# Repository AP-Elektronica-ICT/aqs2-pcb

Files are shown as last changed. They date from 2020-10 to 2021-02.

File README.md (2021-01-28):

# Schema airsensor
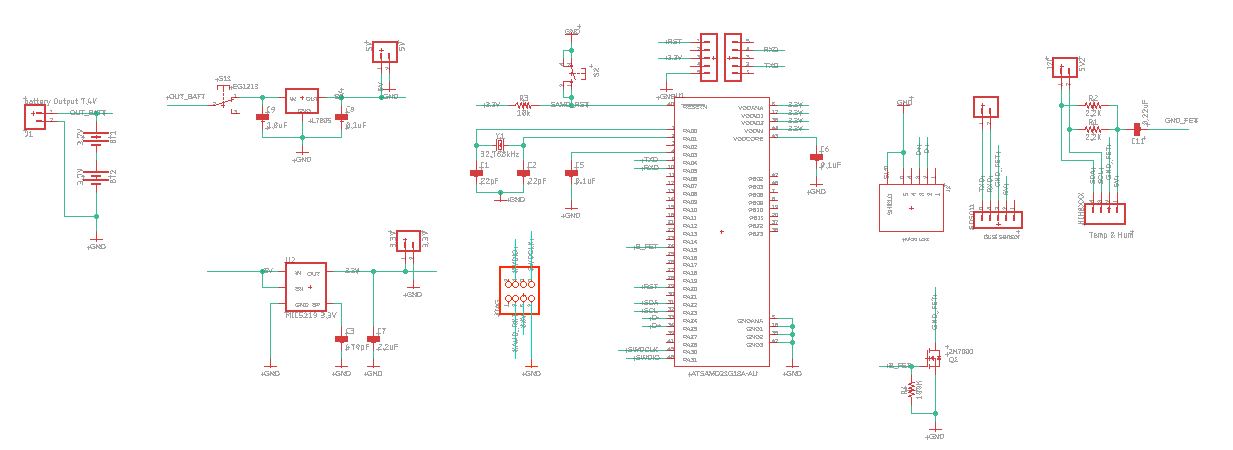
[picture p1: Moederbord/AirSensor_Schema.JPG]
schema airsensor


# Schema LoRaWAN
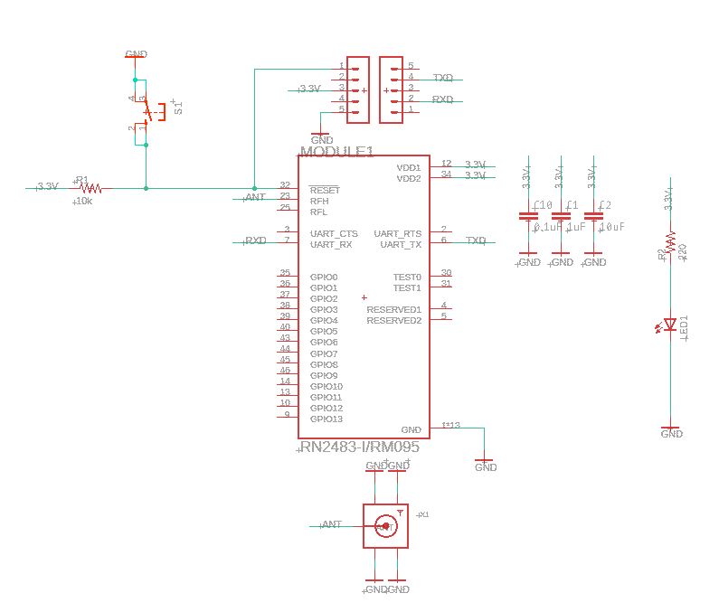
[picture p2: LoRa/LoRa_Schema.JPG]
schema LoRa


# Schema HIH8xxx
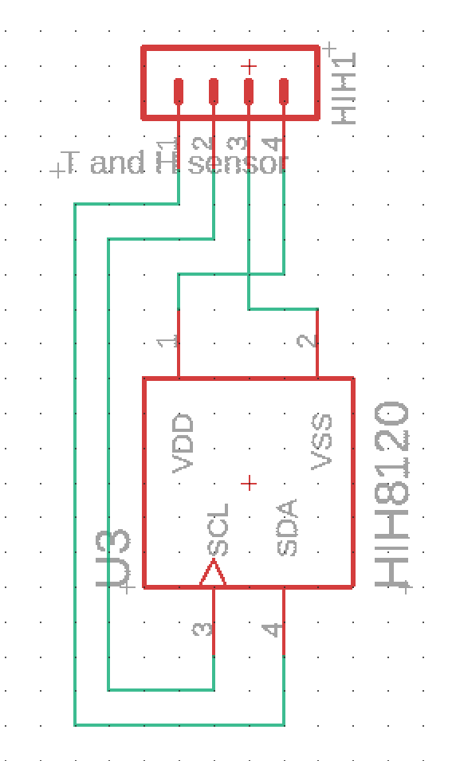
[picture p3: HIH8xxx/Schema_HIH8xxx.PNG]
Schema HIH8xxx


# Schema JTAG
<<<<<<< HEAD
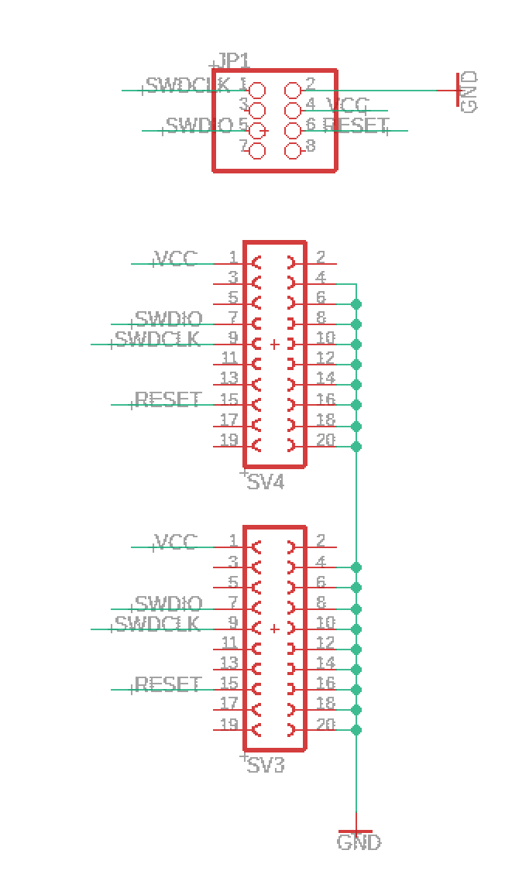
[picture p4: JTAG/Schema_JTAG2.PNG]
schema JTAG

=======
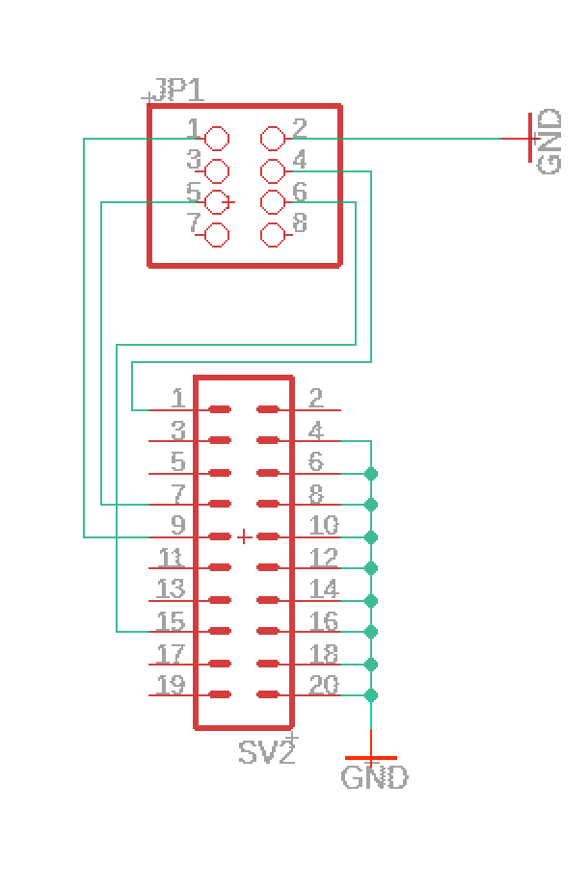
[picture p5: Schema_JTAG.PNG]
schema JTAG

>>>>>>> c74764702c0ad45f76e91693a2fbca707ce8f4d9

# PCB airsensor
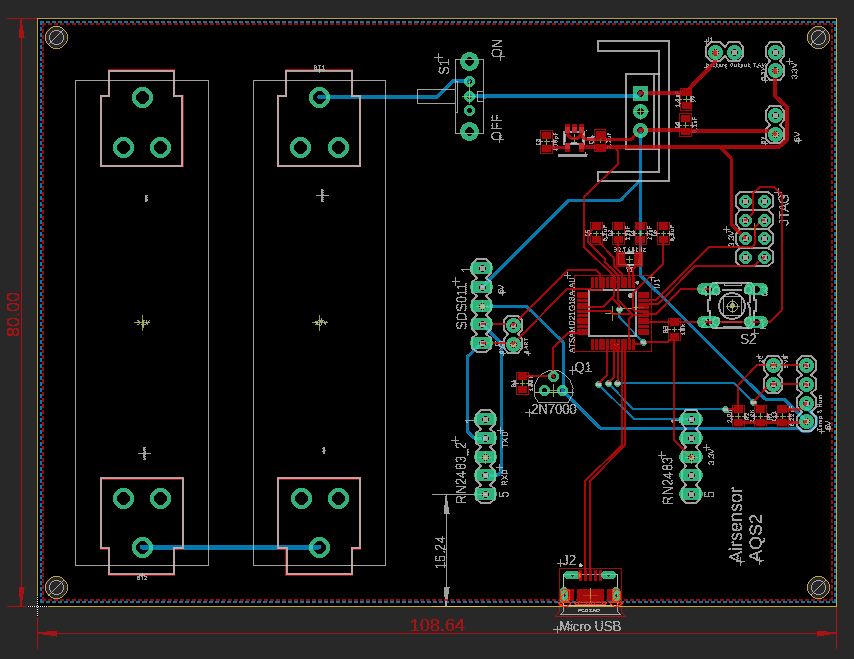
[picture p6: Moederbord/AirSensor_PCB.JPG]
PCB airsensor


# PCB LoRaWAN
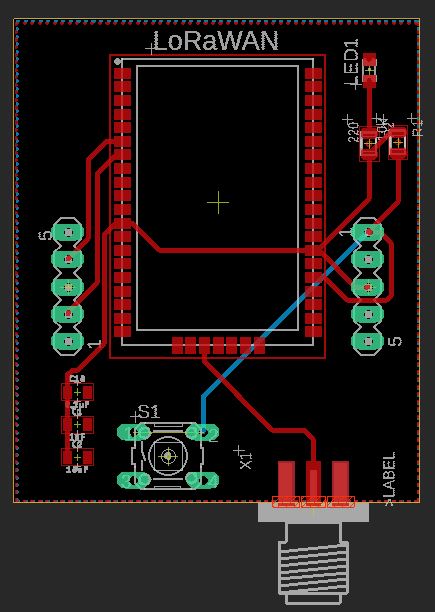
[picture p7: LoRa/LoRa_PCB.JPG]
PCB LoraWAN


# PCB HIH8xxx
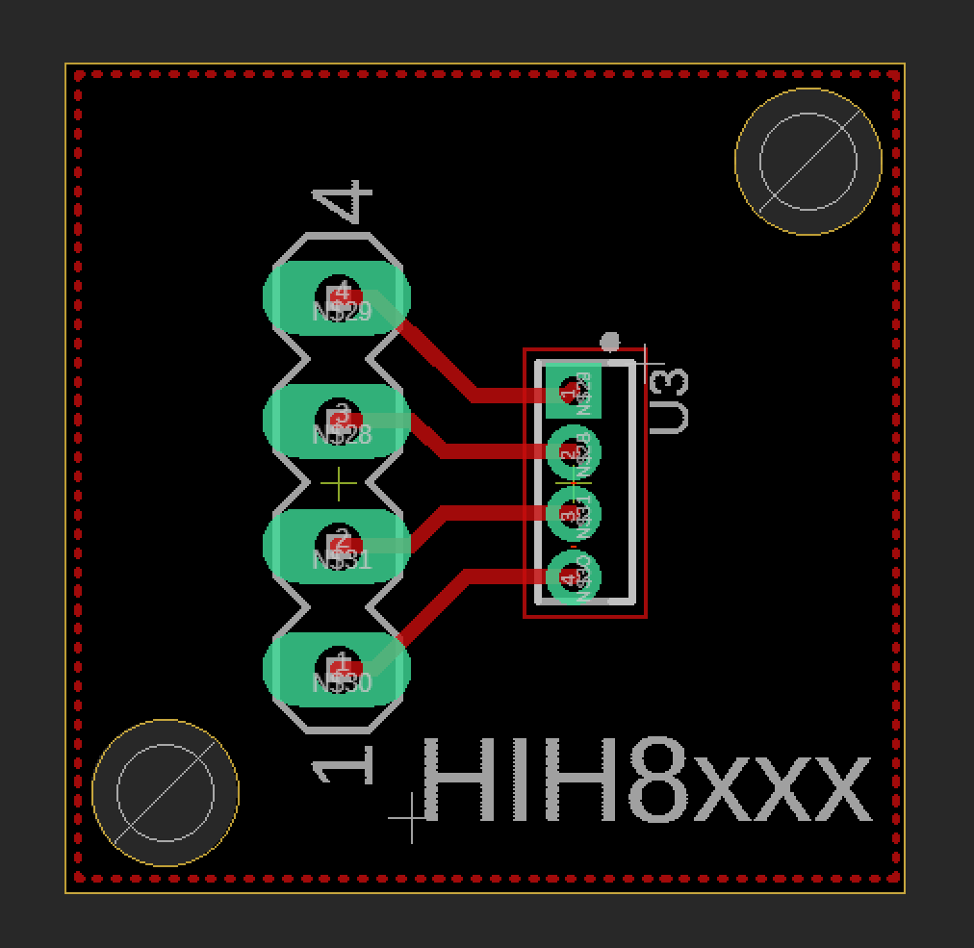
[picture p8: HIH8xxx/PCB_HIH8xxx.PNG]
PCB HIH8xxx


# PCB JTAG
<<<<<<< HEAD
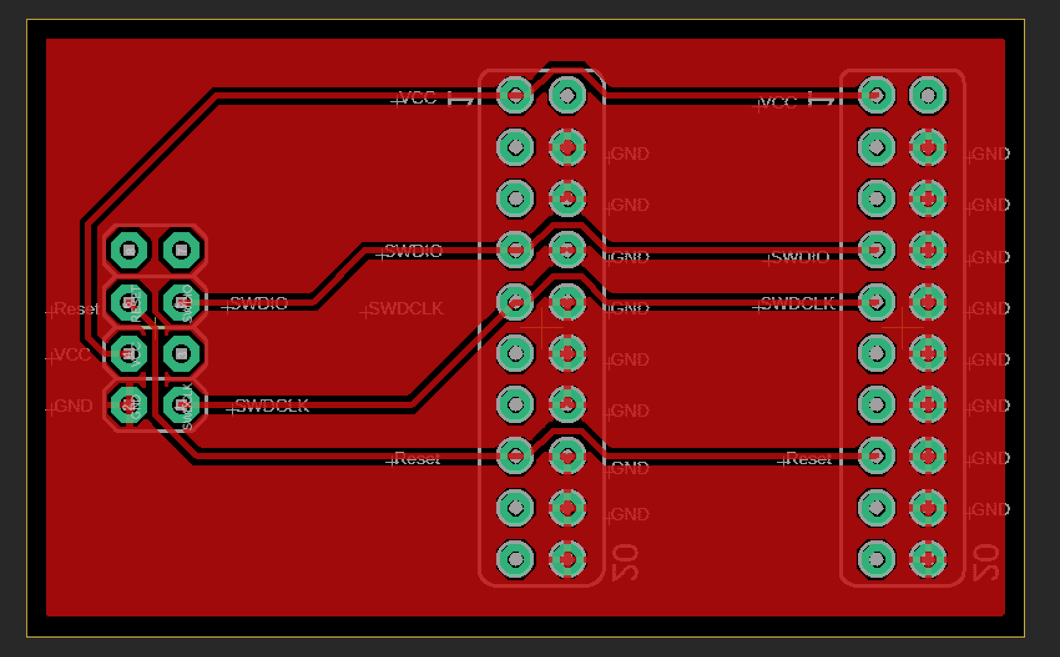
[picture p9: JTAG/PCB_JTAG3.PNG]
PCB JTAG

=======
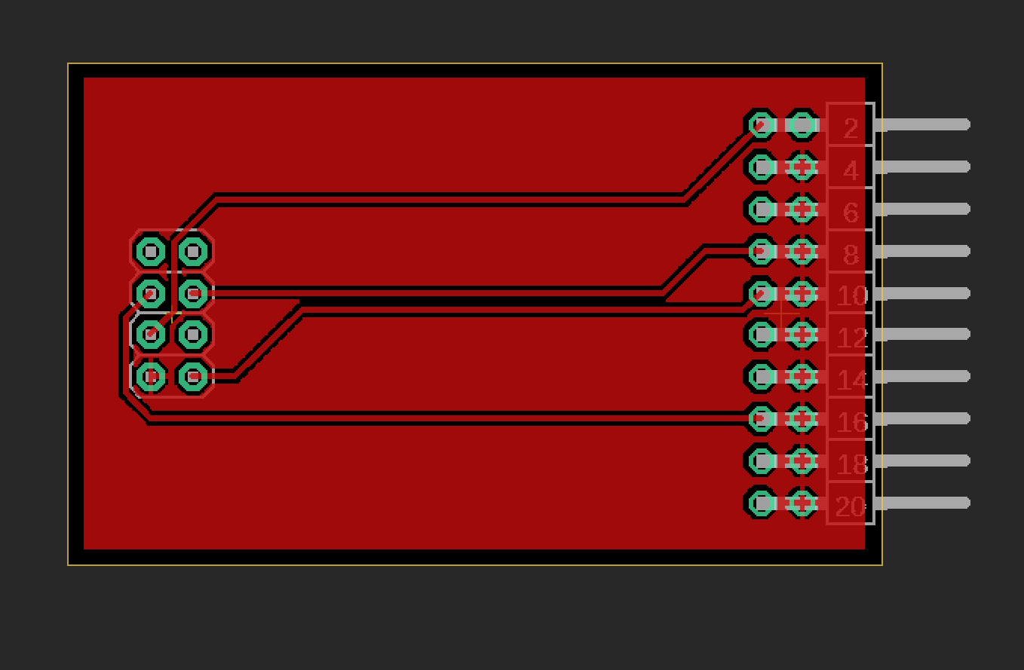
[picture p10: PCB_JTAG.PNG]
PCB JTAG

>>>>>>> c74764702c0ad45f76e91693a2fbca707ce8f4d9

# 3D airsensor
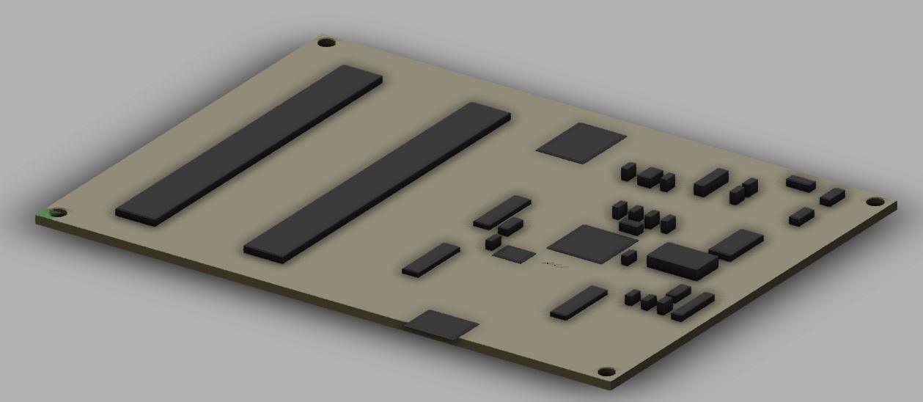
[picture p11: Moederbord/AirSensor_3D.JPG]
3D airsensor


# 3D LoRaWAN
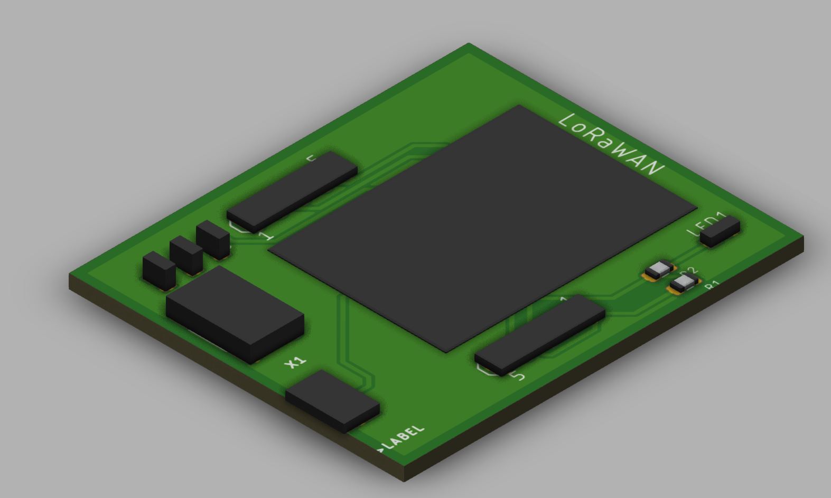
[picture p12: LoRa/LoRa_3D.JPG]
3D LoraWAN


# 3D HIH8xxx
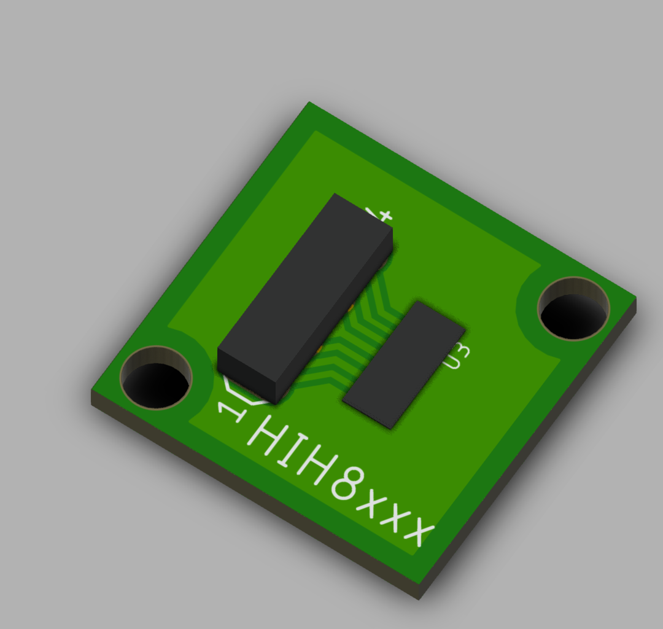
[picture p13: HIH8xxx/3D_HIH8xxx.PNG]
3D HIH8xxx


# 3D JTAG
<<<<<<< HEAD
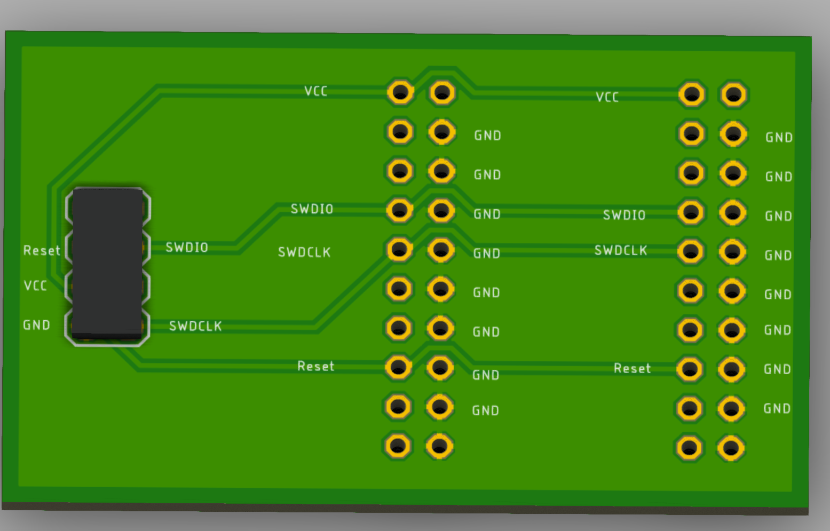
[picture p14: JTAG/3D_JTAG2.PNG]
3D JTAG

=======
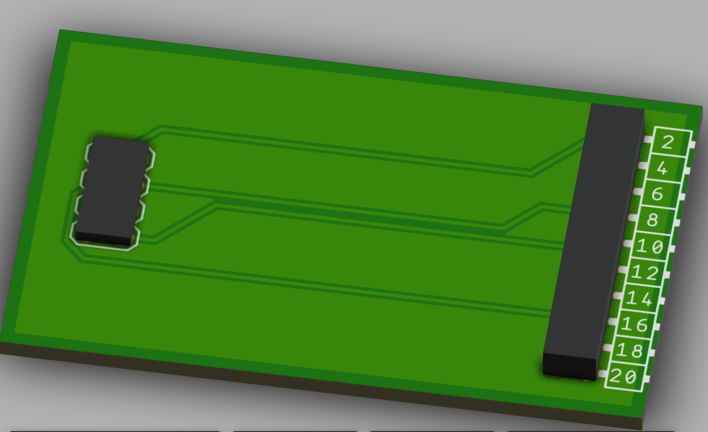
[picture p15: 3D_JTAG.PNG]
3D JTAG


>>>>>>> c74764702c0ad45f76e91693a2fbca707ce8f4d9

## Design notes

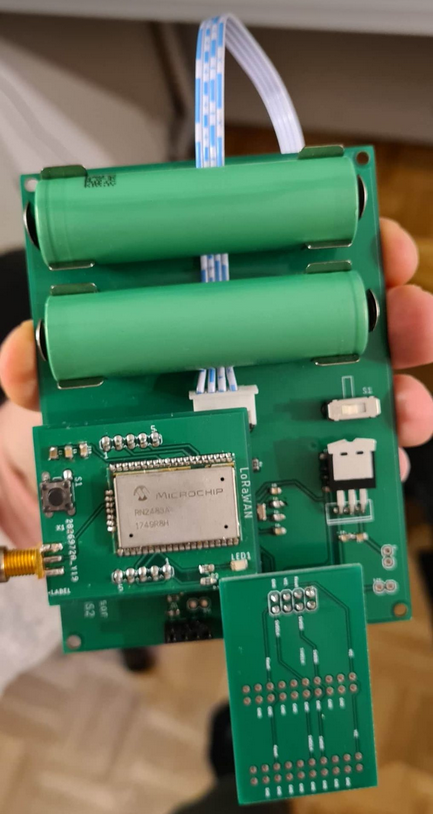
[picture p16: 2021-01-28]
PCB_V2.PNG

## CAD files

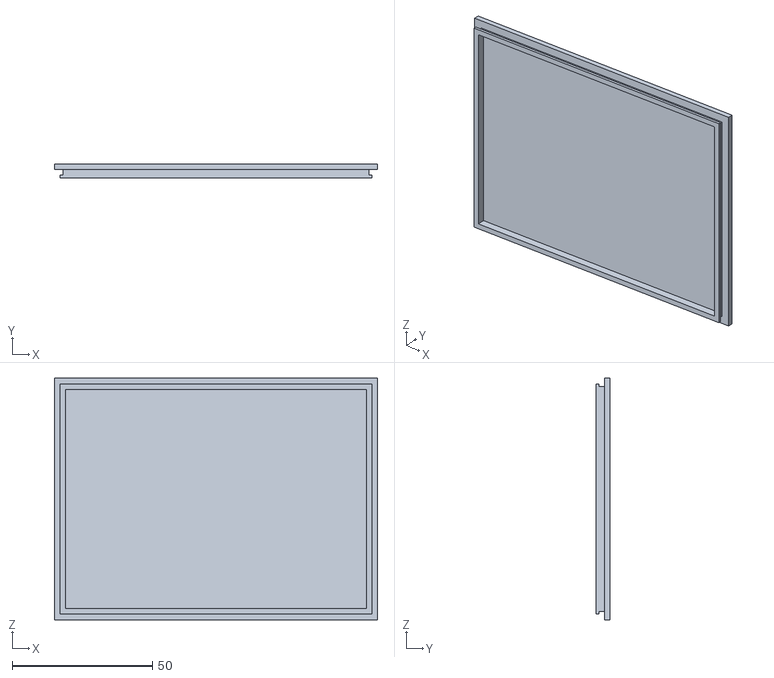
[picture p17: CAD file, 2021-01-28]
frame/cap.stl
115.0 x 5.00 x 86.0

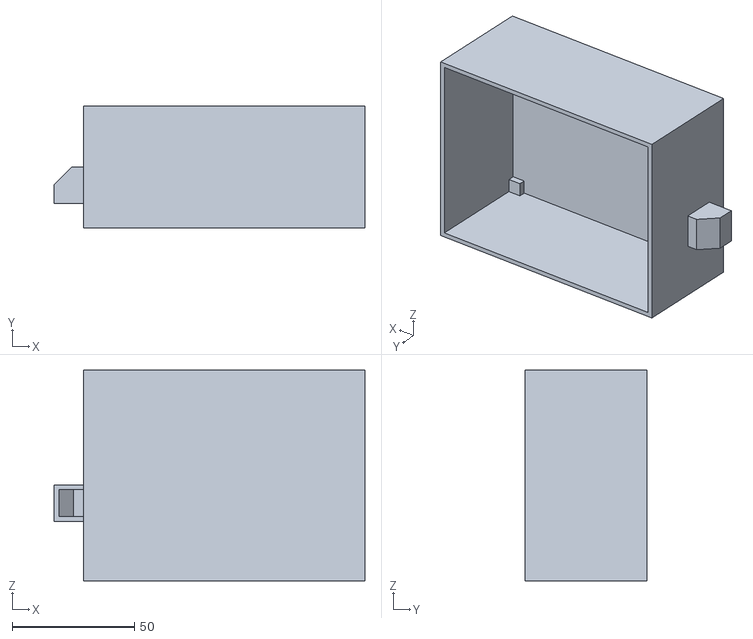
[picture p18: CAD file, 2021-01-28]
frame/box.stl
127.0 x 50.0 x 86.0

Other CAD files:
frame/box.ipt
frame/cap.ipt

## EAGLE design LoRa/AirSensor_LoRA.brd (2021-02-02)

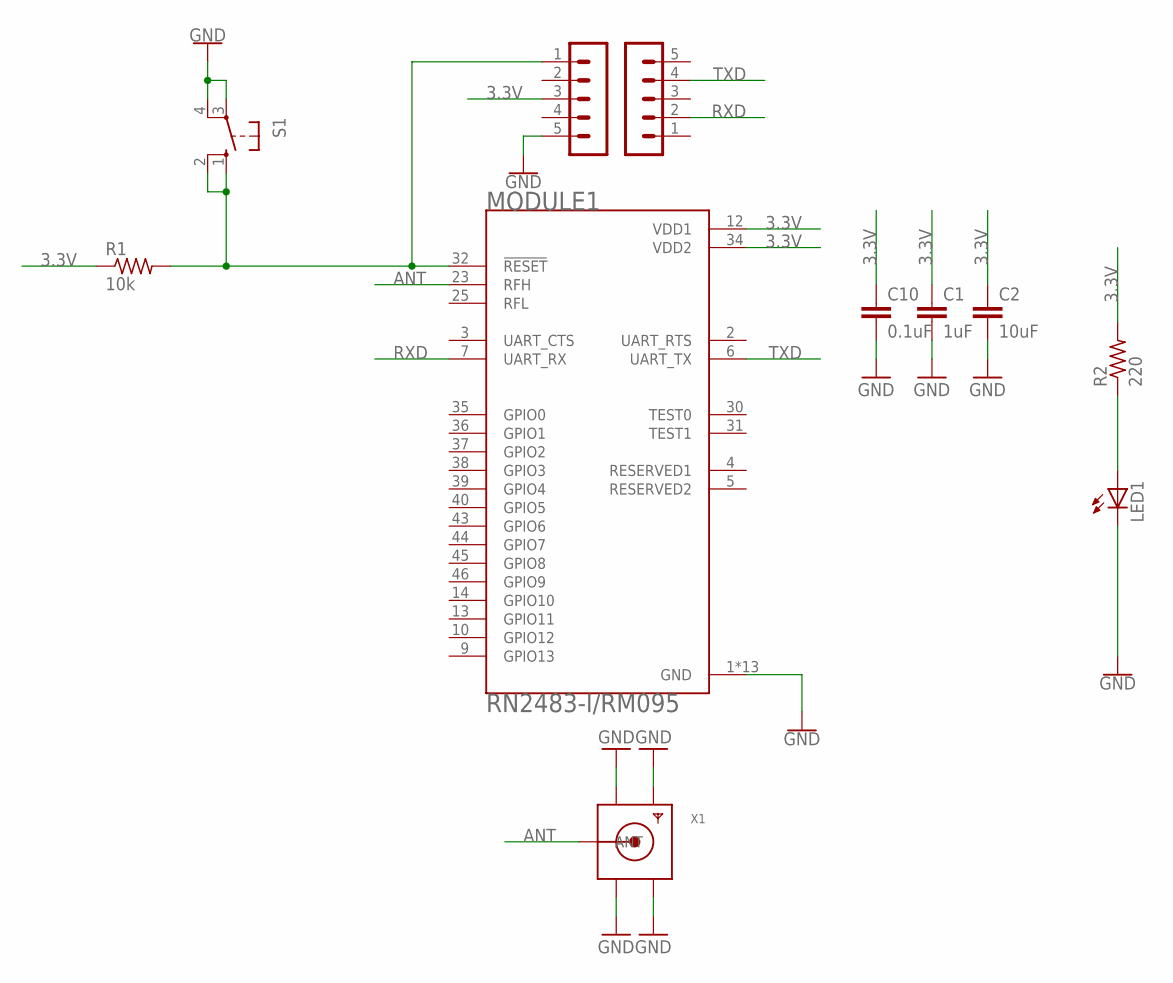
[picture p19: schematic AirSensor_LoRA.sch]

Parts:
C1: 1uF; 0805
C2: 10uF; 0805
C10: 0.1uF; 0805
LED1: LEDCHIPLED_0805; CHIPLED_0805
MODULE1: RN2483-I/RM095; MICROCHIP_RN2483-I/RM095
R1: 10k; RES_0805
R2: 220; RES_0805
RFM95W_1: LoRa_1; MA05-1
RFM95W_2: LoRa_2; MA05-1
S1: 10-XX; B3F-10XX
X1: SMACONNECTOR_EDGE; SMA_EDGELAUNCH

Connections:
3.3V: C1.1, C2.1, C10.1, MODULE1.12 (VDD1), MODULE1.34 (VDD2), R1.1, R2.2, RFM95W_1.3
ANT: MODULE1.23 (RFH), X1.P (ANT)
GND: C1.2, C2.2, C10.2, LED1.C, MODULE1.1 (GND), MODULE1.8 (GND), MODULE1.11 (GND), MODULE1.20 (GND), MODULE1.21 (GND), MODULE1.22 (GND), MODULE1.24 (GND), MODULE1.26 (GND), MODULE1.27 (GND), MODULE1.28 (GND), MODULE1.33 (GND), MODULE1.41 (GND), MODULE1.47 (GND), RFM95W_1.5, S1.3, S1.4 (P1), X1.GND@1 (GND4), X1.GND@2 (GND3), X1.GND@3 (GND2), X1.GND@4 (GND1)
unnamed: LED1.A, R2.1
unnamed: MODULE1.32 (!RESET), R1.2, RFM95W_1.1, S1.1 (S), S1.2 (S1)
RXD: MODULE1.7 (UART_RX), RFM95W_2.2
TXD: MODULE1.6 (UART_TX), RFM95W_2.4

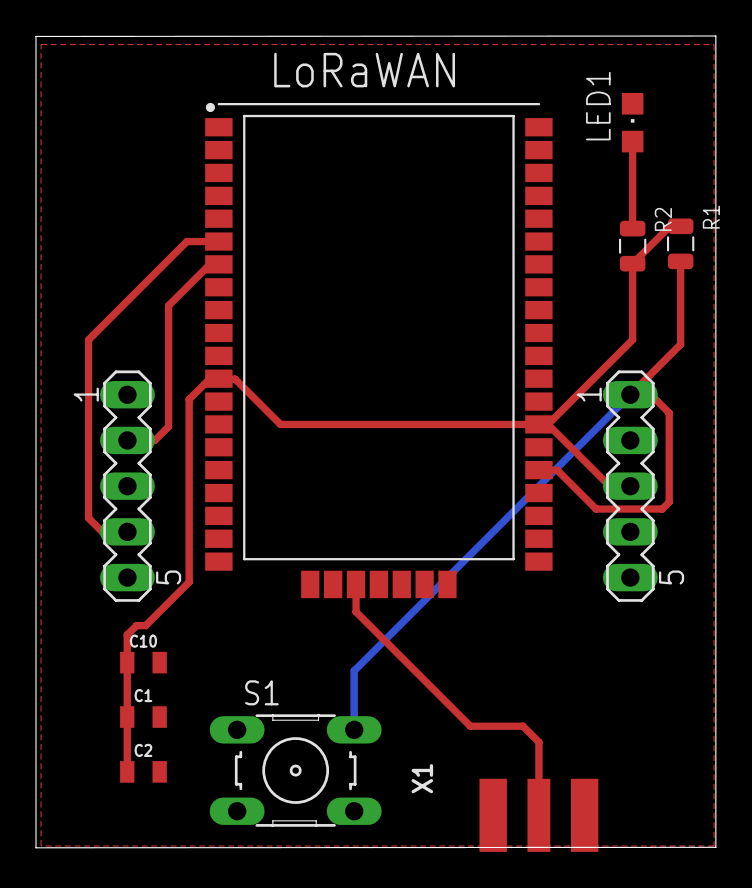
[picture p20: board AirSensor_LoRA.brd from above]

Board: 2 copper layers, 37.8 x 45.1 mm, 11 parts (0 on the bottom side), 7 nets.

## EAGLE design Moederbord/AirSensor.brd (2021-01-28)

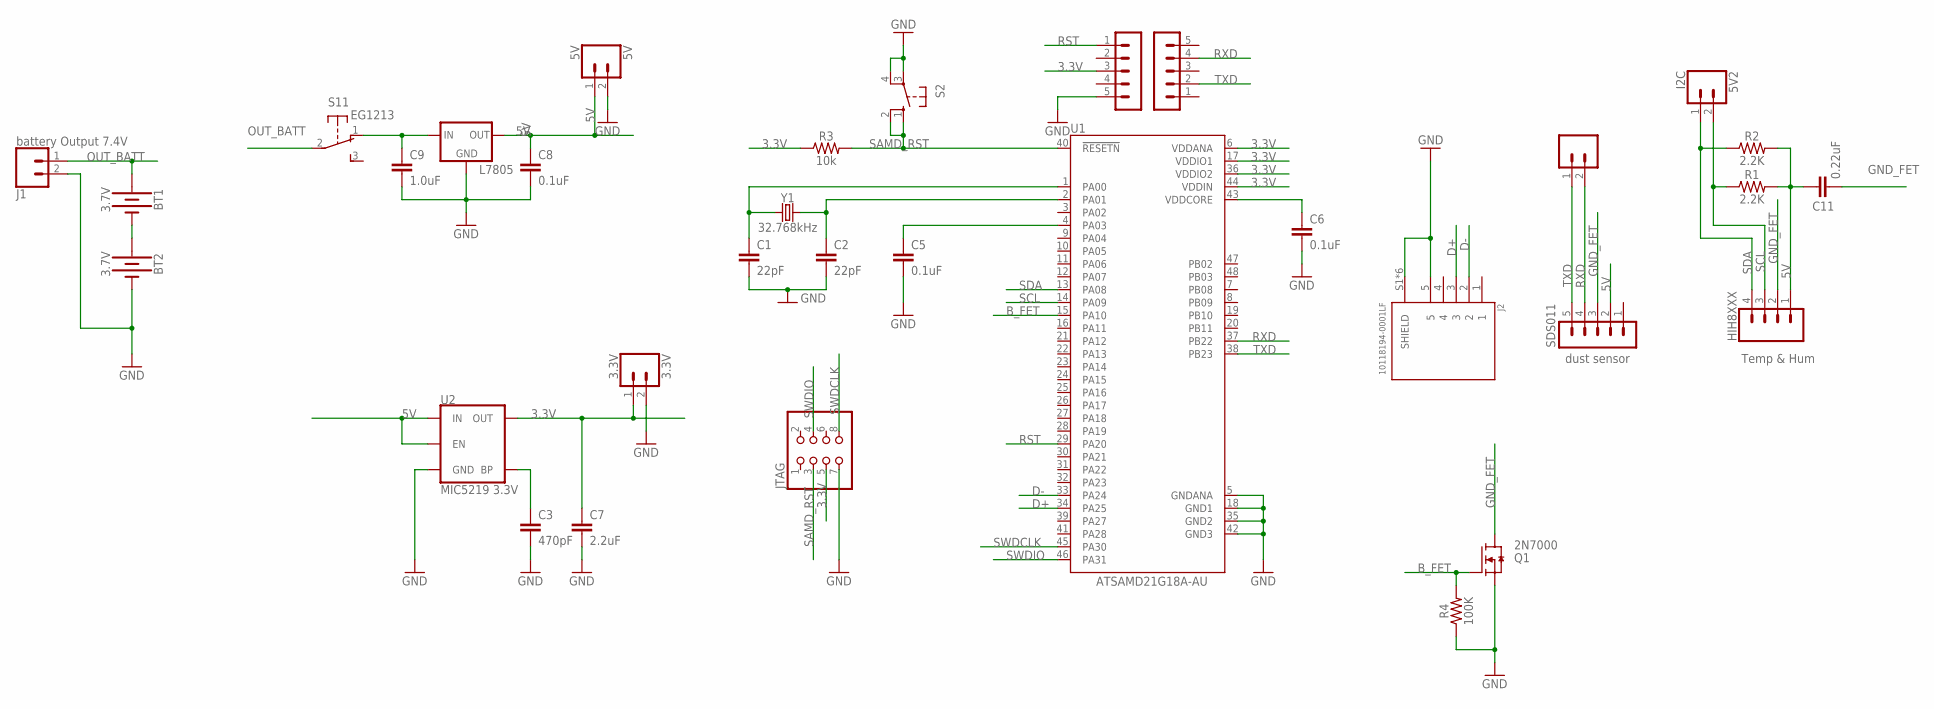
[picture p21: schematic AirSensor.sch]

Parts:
3.3V: 3.3V; 1X02
5V: 5V; 1X02
5V1: UART; 1X02
5V2: I2C; 1X02
BT1, BT2: 3.7V; BATTERY_18650-HOLDER
C1, C2: 22pF; 0805
C3: 470pF; 0805
C5, C6, C8: 0.1uF; 0805
C7: 2.2uF; 0805
C9: 1.0uF; 0805
C11: 0.22uF; 0805
HIH8XXX: Temp & Hum; 1X04
J1: battery Output 7.4V; 1X02
J2: 10118194-0001LF; AMPHENOL_10118194-0001LF
JTAG: PINHD-2X4; 2X04
L7805: V_REG_78XXSINK; TO220-IGO
Q1: 2N7000; TO92
R1, R2: 2.2K; 0805
R3: 10k; 0805
R4: 100K; 0805
RN2483: LoRa1; MA05-1
RN2483_2: LoRa_2; MA05-1
S1: EG1213
S2: 10-XX; B3F-10XX
SDS011: dust sensor; MA05-1
U1: ATSAMD21G18A-AU; QFP50P900X900X120-48N
U2: MIC5219 3.3V; SOT23-5
Y1: 32.768kHz; CRYSTAL-SMD-3.2X1.5MM

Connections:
3.3V: 3.3V.1, C7.1, JTAG.5, R3.1, RN2483.3, U1.6 (VDDANA), U1.17 (VDDIO1), U1.36 (VDDIO2), U1.44 (VDDIN), U2.5 (OUT)
5V: 5V.1, C8.1, C11.1, HIH8XXX.1, L7805.OUT, R1.2, R2.2, SDS011.2, U2.1 (IN), U2.3 (EN)
B_FET: Q1.2 (G), R4.2, U1.15 (PA10)
D+: J2.3, U1.34 (PA25)
D-: J2.2, U1.33 (PA24)
GND: 3.3V.2, 5V.2, BT2.GND@1 (-), C1.2, C2.2, C3.2, C5.2, C6.2, C7.2, C8.2, C9.2, J1.2, J2.5, J2.S1 (SHIELD), J2.S2 (SHIELD), J2.S3 (SHIELD), J2.S4 (SHIELD), J2.S5 (SHIELD), J2.S6 (SHIELD), JTAG.7, L7805.GND, Q1.1 (S), R4.1, RN2483.5, S2.3, S2.4 (P1), U1.5 (GNDANA), U1.18 (GND1), U1.35 (GND2), U1.42 (GND3), U2.2 (GND)
GND_FET: C11.2, HIH8XXX.2, Q1.3 (D), SDS011.3
unnamed: C5.1, U1.4 (PA03)
unnamed: C6.1, U1.43 (VDDCORE)
unnamed: C1.1, U1.1 (PA00), Y1.P$1 (1)
unnamed: C3.1, U2.4 (BP)
unnamed: BT1.GND@1 (-), BT2.PWR@1 (+)
unnamed: C2.1, U1.2 (PA01), Y1.P$2 (2)
OUT_BATT: BT1.PWR@1 (+), C9.1, J1.1, L7805.IN, S1.1 (O), S1.2
RST: RN2483.1, U1.29 (PA20)
RXD: 5V1.2, RN2483_2.4, SDS011.4, U1.37 (PB22)
SAMD_RST: JTAG.3, R3.2, S2.1 (S), S2.2 (S1), U1.40 (!RESETN)
SCL: 5V2.2, HIH8XXX.3, R1.1, U1.14 (PA09)
SDA: 5V2.1, HIH8XXX.4, R2.1, U1.13 (PA08)
SWDCLK: JTAG.8, U1.45 (PA30)
SWDIO: JTAG.4, U1.46 (PA31)
TXD: 5V1.1, RN2483_2.2, SDS011.5, U1.38 (PB23)

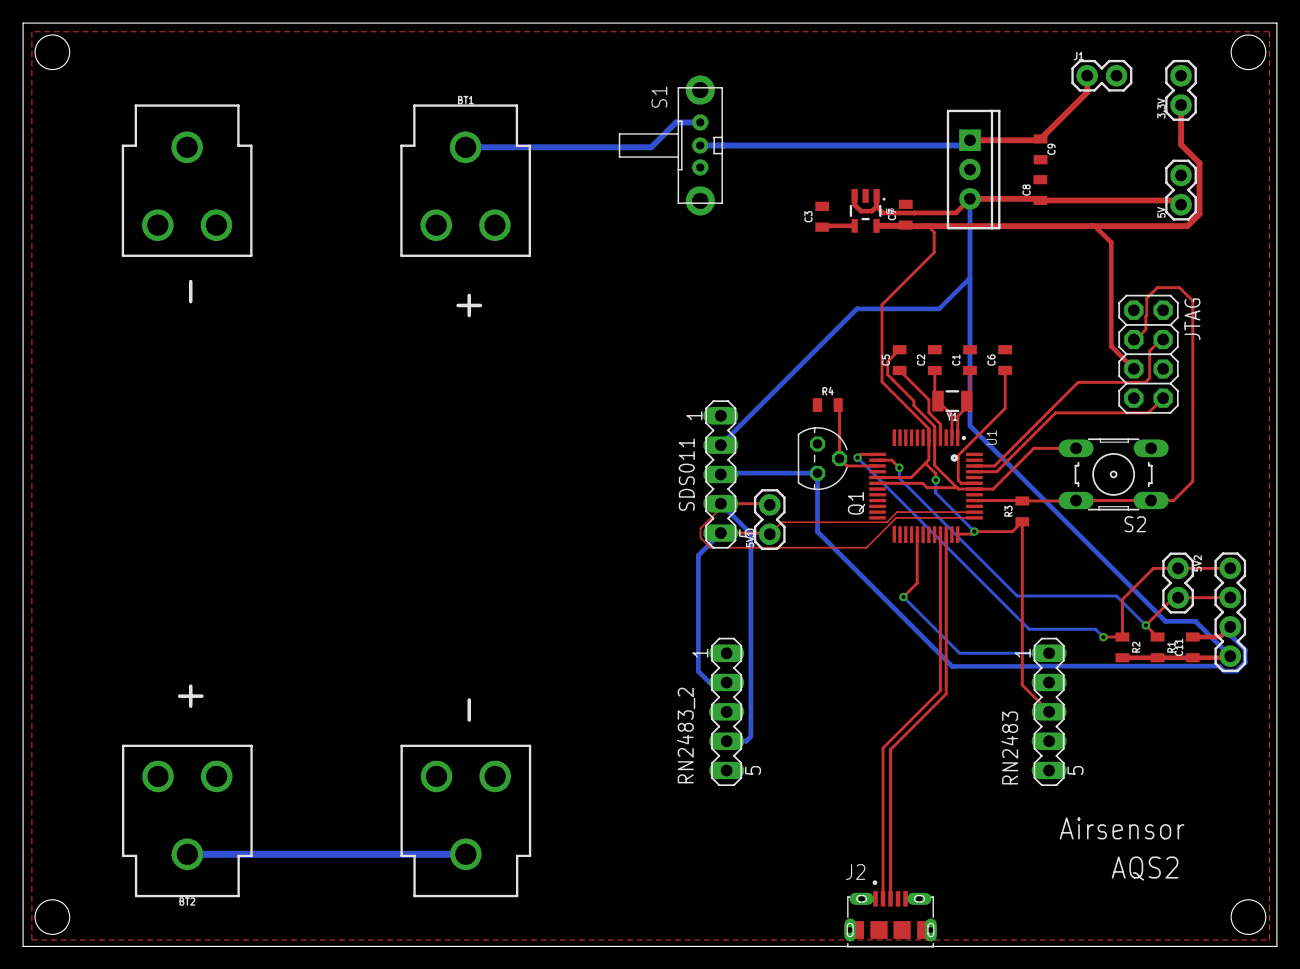
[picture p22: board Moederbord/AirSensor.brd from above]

Board: 2 copper layers, 108.6 x 80.0 mm, 33 parts (0 on the bottom side), 22 nets.

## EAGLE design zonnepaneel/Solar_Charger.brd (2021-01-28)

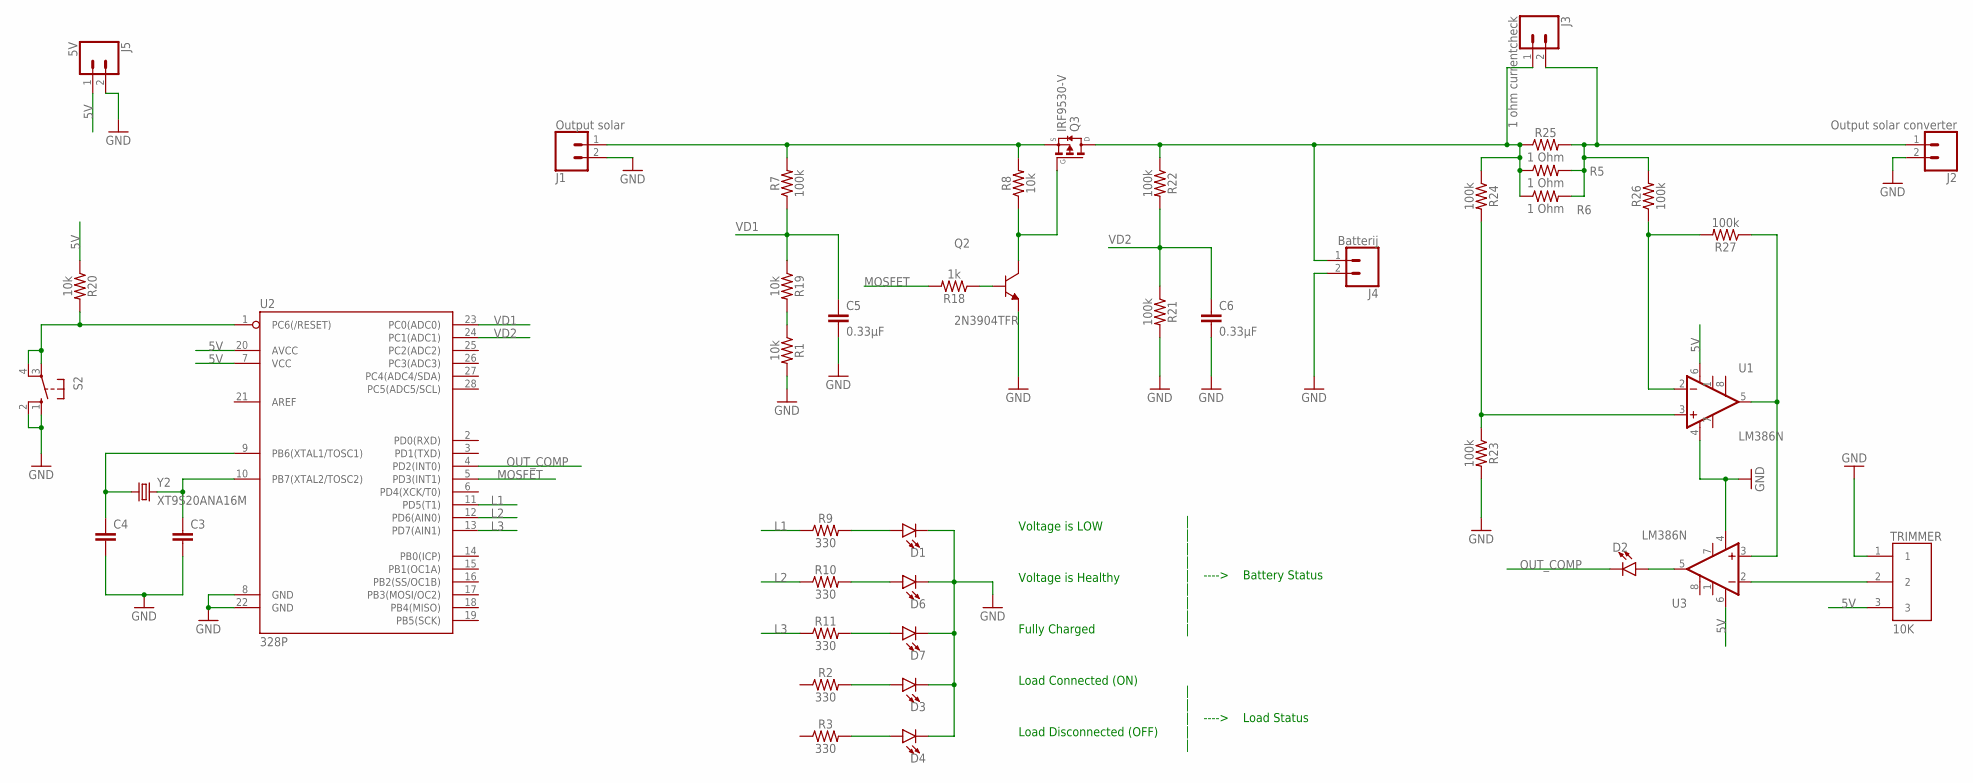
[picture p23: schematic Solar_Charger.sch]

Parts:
C3, C4: C2.5/5; C2.5-5
C5, C6: 0.33µF; C2.5-5
D1, D2, D3, D4, D6, D7: LED-3MM-NO_SILK; LED_3MM-NS
J1: Output solar; 1X02
J2: Output solar converter; 1X02
J3: 1 ohm currentcheck; 1X02
J4: Batterij; 1X02
J5: 5V; 1X02
Q2: 2N3904TFR; TO92254P520H877-3
Q3: IRF9530-V; TO220V
R1, R8, R19, R20: 10k; AXIAL-0.3
R2, R3, R9, R10, R11: 330; AXIAL-0.3
R5, R6, R25: 1 Ohm; AXIAL-0.3
R7, R21, R22, R23, R24, R26, R27: 100k; AXIAL-0.3
R18: 1k; AXIAL-0.3
S2: 10-XX; B3F-10XX
TRIMMER: 10K; TRIM_404806347006
U1, U3: LM386N; DIP08
U2: 328P; DIP28
Y2: XT9S20ANA16M; XTAL_XT9S20ANA16M

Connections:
5V: J5.1, R20.P$1 (1), TRIMMER.3, U1.6 (V+), U2.7 (VCC), U2.20 (AVCC), U3.6 (V+)
GND: C3.2, C4.2, C5.2, C6.2, D1.K (C), D3.K (C), D4.K (C), D6.K (C), D7.K (C), J1.2, J2.2, J4.2, J5.2, Q2.1 (E), R1.P$2 (2), R21.P$2 (2), R23.P$2 (2), S2.1 (S), S2.2 (S1), TRIMMER.1, U1.4 (V-), U2.8 (GND), U2.22 (GND), U3.4 (V-)
GND1: R20.P$2 (2), S2.3, S2.4 (P1), U2.1 (PC6(/RESET))
L1: R9.P$1 (1), U2.11 (PD5(T1))
L2: R10.P$1 (1), U2.12 (PD6(AIN0))
L3: R11.P$1 (1), U2.13 (PD7(AIN1))
MOSFET: R18.P$2 (2), U2.5 (PD3(INT1))
unnamed: J1.1, Q3.3 (S), R7.P$2 (2), R8.P$2 (2)
unnamed: D3.A, R2.P$2 (2)
unnamed: D4.A, R3.P$2 (2)
unnamed: R23.P$1 (1), R24.P$2 (2), U1.3 (+IN)
unnamed: R26.P$1 (1), R27.P$2 (2), U1.2 (-IN)
unnamed: R1.P$1 (1), R19.P$2 (2)
unnamed: C4.1, U2.9 (PB6(XTAL1/TOSC1)), Y2.1
unnamed: C3.1, U2.10 (PB7(XTAL2/TOSC2)), Y2.2
unnamed: Q2.2 (B), R18.P$1 (1)
unnamed: Q2.3 (C), Q3.1 (G), R8.P$1 (1)
unnamed: J3.1, J4.1, Q3.2 (D), R5.P$1 (1), R6.P$1 (1), R22.P$1 (1), R24.P$1 (1), R25.P$1 (1)
unnamed: R27.P$1 (1), U1.5 (OUT), U3.3 (+IN)
unnamed: TRIMMER.2, U3.2 (-IN)
unnamed: D2.A, U3.5 (OUT)
unnamed: J2.1, J3.2, R5.P$2 (2), R6.P$2 (2), R25.P$2 (2), R26.P$2 (2)
unnamed: D1.A, R9.P$2 (2)
unnamed: D6.A, R10.P$2 (2)
unnamed: D7.A, R11.P$2 (2)
OUT_COMP: D2.K (C), U2.4 (PD2(INT0))
VD1: C5.1, R7.P$1 (1), R19.P$1 (1), U2.23 (PC0(ADC0))
VD2: C6.1, R21.P$1 (1), R22.P$2 (2), U2.24 (PC1(ADC1))

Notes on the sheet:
Voltage is LOW
Voltage is Healthy
Fully Charged
Load Connected (ON)
Load Disconnected (OFF)
| | | | | ----> Battery Status | | | |
| | | ----> Load Status | |

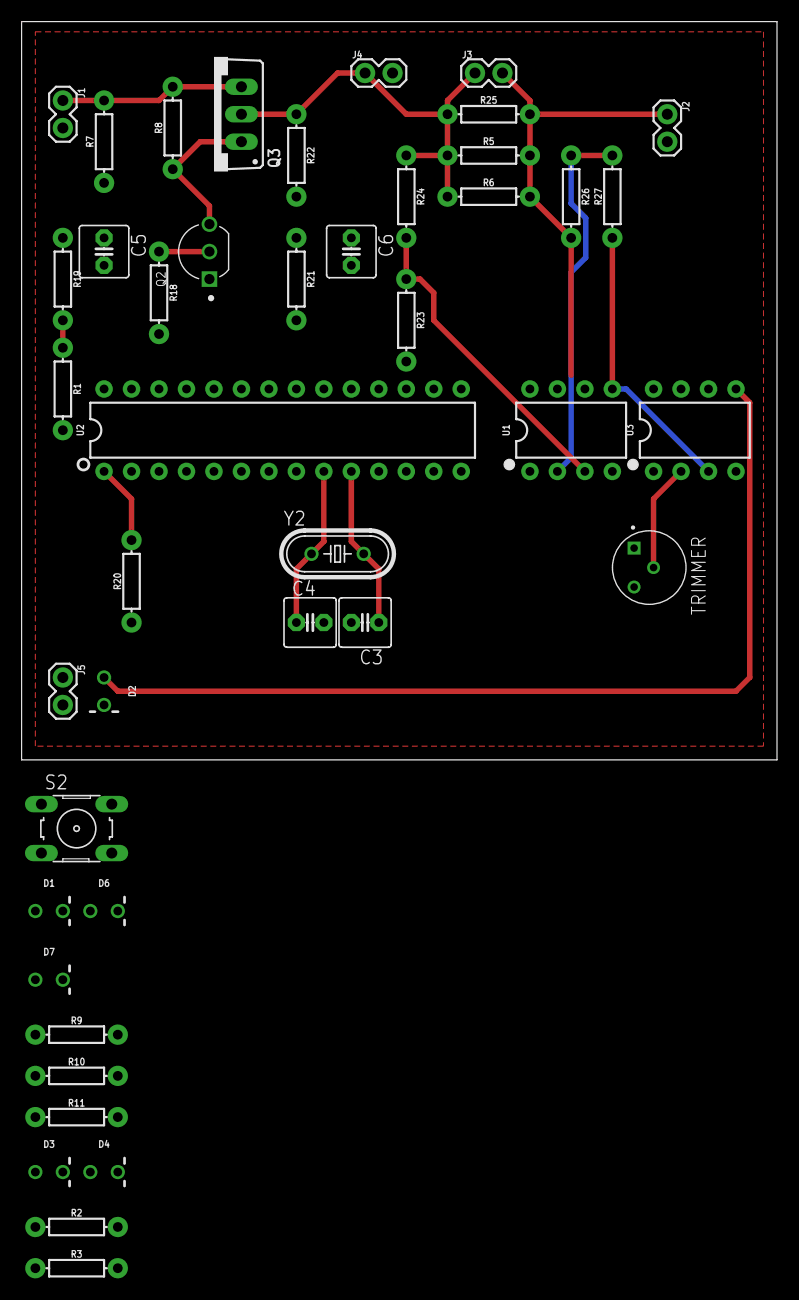
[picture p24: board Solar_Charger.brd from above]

Board: 2 copper layers, 69.8 x 68.2 mm, 43 parts (0 on the bottom side), 28 nets.

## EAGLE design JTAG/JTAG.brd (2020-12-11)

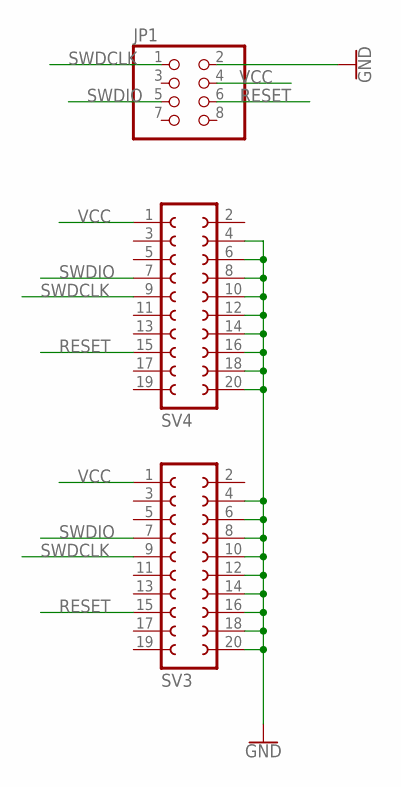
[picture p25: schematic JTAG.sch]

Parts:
JP1: PINHD-2X4; 2X04
SV3, SV4: FE10-2

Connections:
GND: JP1.2, SV3.4, SV3.6, SV3.8, SV3.10, SV3.12, SV3.14, SV3.16, SV3.18, SV3.20, SV4.4, SV4.6, SV4.8, SV4.10, SV4.12, SV4.14, SV4.16, SV4.18, SV4.20
RESET: JP1.6, SV3.15, SV4.15
SWDCLK: JP1.1, SV3.9, SV4.9
SWDIO: JP1.5, SV3.7, SV4.7
VCC: JP1.4, SV3.1, SV4.1

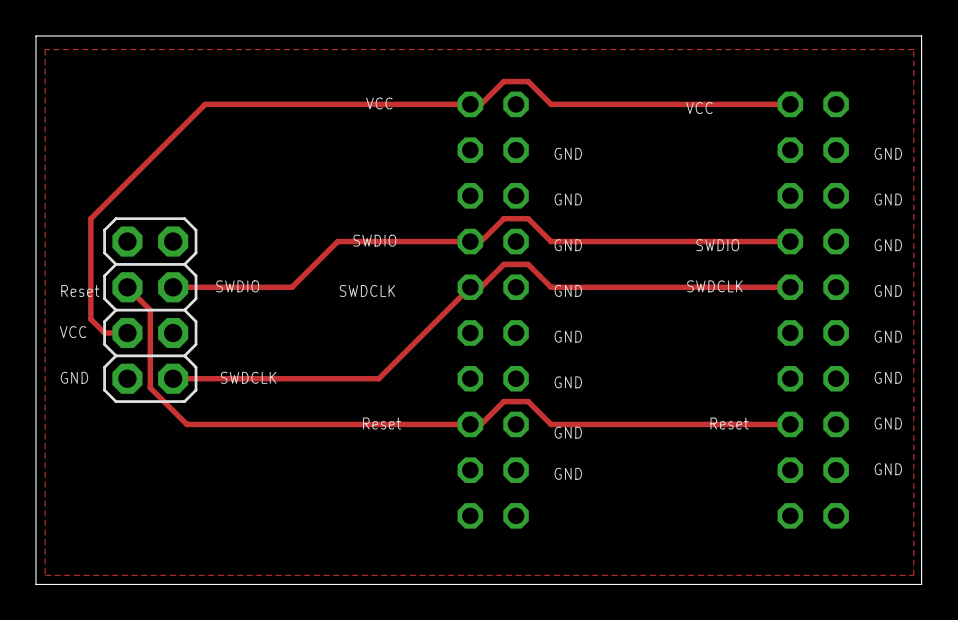
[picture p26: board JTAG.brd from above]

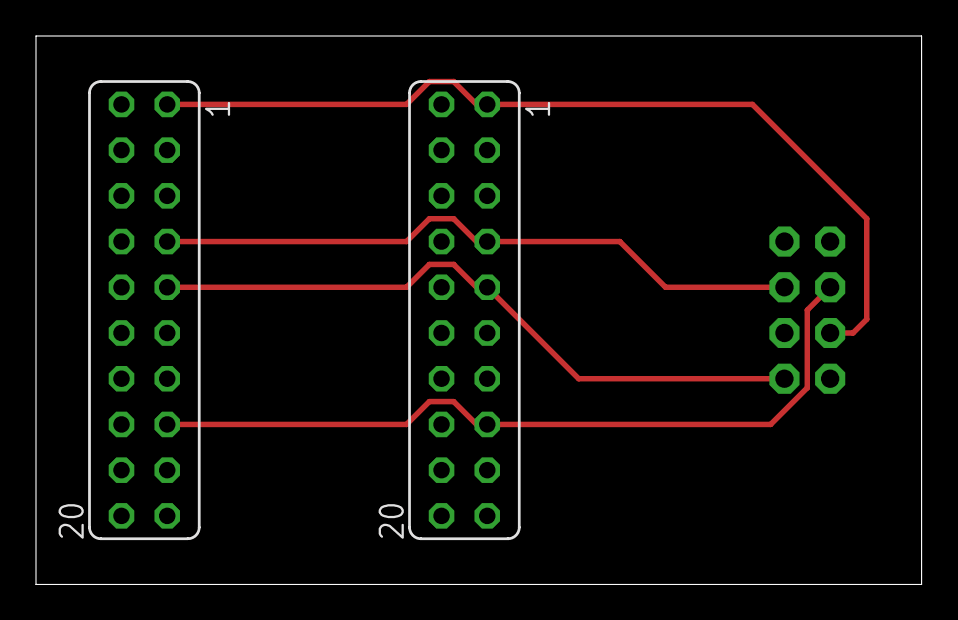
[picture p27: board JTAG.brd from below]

Board: 2 copper layers, 49.2 x 30.5 mm, 3 parts (2 on the bottom side), 5 nets.

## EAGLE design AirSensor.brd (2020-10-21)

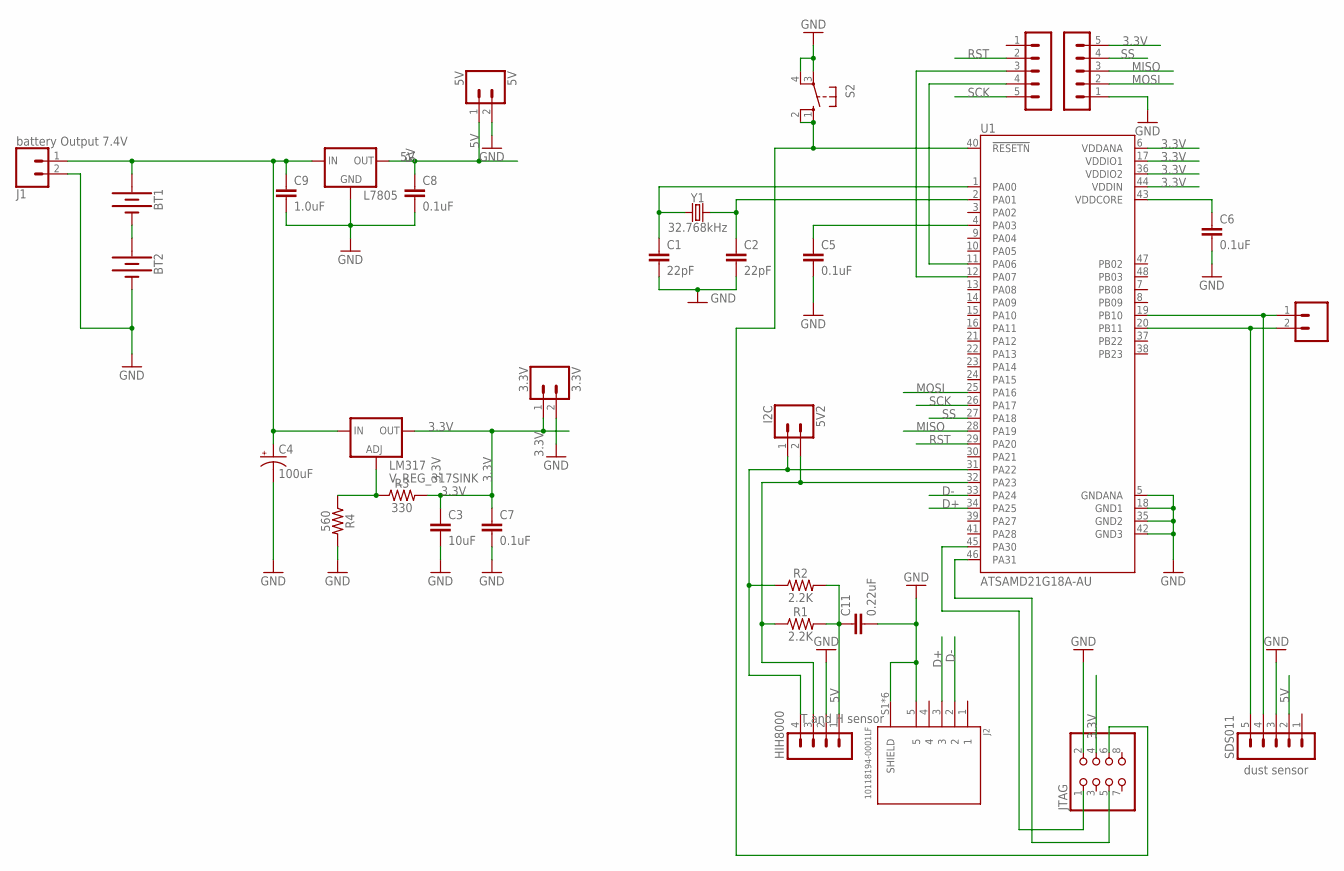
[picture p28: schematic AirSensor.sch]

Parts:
3.3V: 3.3V; 1X02
5V: 5V; 1X02
5V1: UART; 1X02
5V2: I2C; 1X02
BT1, BT2: BATTERY-18650; BATTERY_18650-HOLDER
C1, C2: 22pF; 0805
C3: 10uF; 0805
C4: 100uF; CPOL-RADIAL-2.5MM-6.5MM
C5, C6, C7, C8: 0.1uF; 0805
C9: 1.0uF; 0805
C11: 0.22uF; 0805
HIH8000: T and H sensor; MA04-1
J1: battery Output 7.4V; 1X02
J2: 10118194-0001LF; AMPHENOL_10118194-0001LF
JTAG: PINHD-2X4; 2X04
L7805: V_REG_78XXSINK; TO220-IGO
LM317: V_REG_317SINK; TO220-ADJ
R1, R2: 2.2K; 0805
R3: 330; 0805
R4: 560; 0805
RFM95W: LoRa1; MA05-1
RFM95W_2: LoRa_2; MA05-1
S2: 10-XX; B3F-10XX
SDS011: dust sensor; MA05-1
U1: ATSAMD21G18A-AU; QFP50P900X900X120-48N
Y1: 32.768kHz; CRYSTAL-SMD-3.2X1.5MM

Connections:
3.3V: 3.3V.1, C3.1, C7.1, JTAG.4, LM317.OUT, R3.2, RFM95W_2.5, U1.6 (VDDANA), U1.17 (VDDIO1), U1.36 (VDDIO2), U1.44 (VDDIN)
5V: 5V.1, C8.1, C11.1, HIH8000.1, L7805.OUT, R1.2, R2.2, SDS011.2
D+: J2.3, U1.34 (PA25)
D-: J2.2, U1.33 (PA24)
GND: 3.3V.2, 5V.2, BT2.GND@1 (-), C1.2, C2.2, C3.2, C4.2 (-), C5.2, C6.2, C7.2, C8.2, C9.2, C11.2, HIH8000.2, J1.2, J2.5, J2.S1 (SHIELD), J2.S2 (SHIELD), J2.S3 (SHIELD), J2.S4 (SHIELD), J2.S5 (SHIELD), J2.S6 (SHIELD), JTAG.2, L7805.GND, R4.2, RFM95W_2.1, S2.3, S2.4 (P1), SDS011.3, U1.5 (GNDANA), U1.18 (GND1), U1.35 (GND2), U1.42 (GND3)
MISO: RFM95W_2.3, U1.28 (PA19)
MOSI: RFM95W_2.2, U1.25 (PA16)
unnamed: 5V2.2, HIH8000.3, R1.1, U1.32 (PA23)
unnamed: 5V1.1, SDS011.4, U1.19 (PB10)
unnamed: 5V1.2, SDS011.5, U1.20 (PB11)
unnamed: C5.1, U1.4 (PA03)
unnamed: C6.1, U1.43 (VDDCORE)
unnamed: C1.1, U1.1 (PA00), Y1.P$1 (1)
unnamed: LM317.ADJ, R3.1, R4.1
unnamed: BT1.GND@1 (-), BT2.PWR@1 (+)
unnamed: C2.1, U1.2 (PA01), Y1.P$2 (2)
unnamed: JTAG.6, S2.1 (S), S2.2 (S1), U1.40 (!RESETN)
unnamed: BT1.PWR@1 (+), C4.1 (+), C9.1, J1.1, L7805.IN, LM317.IN
unnamed: 5V2.1, HIH8000.4, R2.1, U1.31 (PA22)
unnamed: RFM95W.4, U1.11 (PA06)
unnamed: JTAG.1, U1.45 (PA30)
unnamed: JTAG.5, U1.46 (PA31)
unnamed: RFM95W.3, U1.12 (PA07)
RST: RFM95W.2, U1.29 (PA20)
SCK: RFM95W.5, U1.26 (PA17)
SS: RFM95W_2.4, U1.27 (PA18)

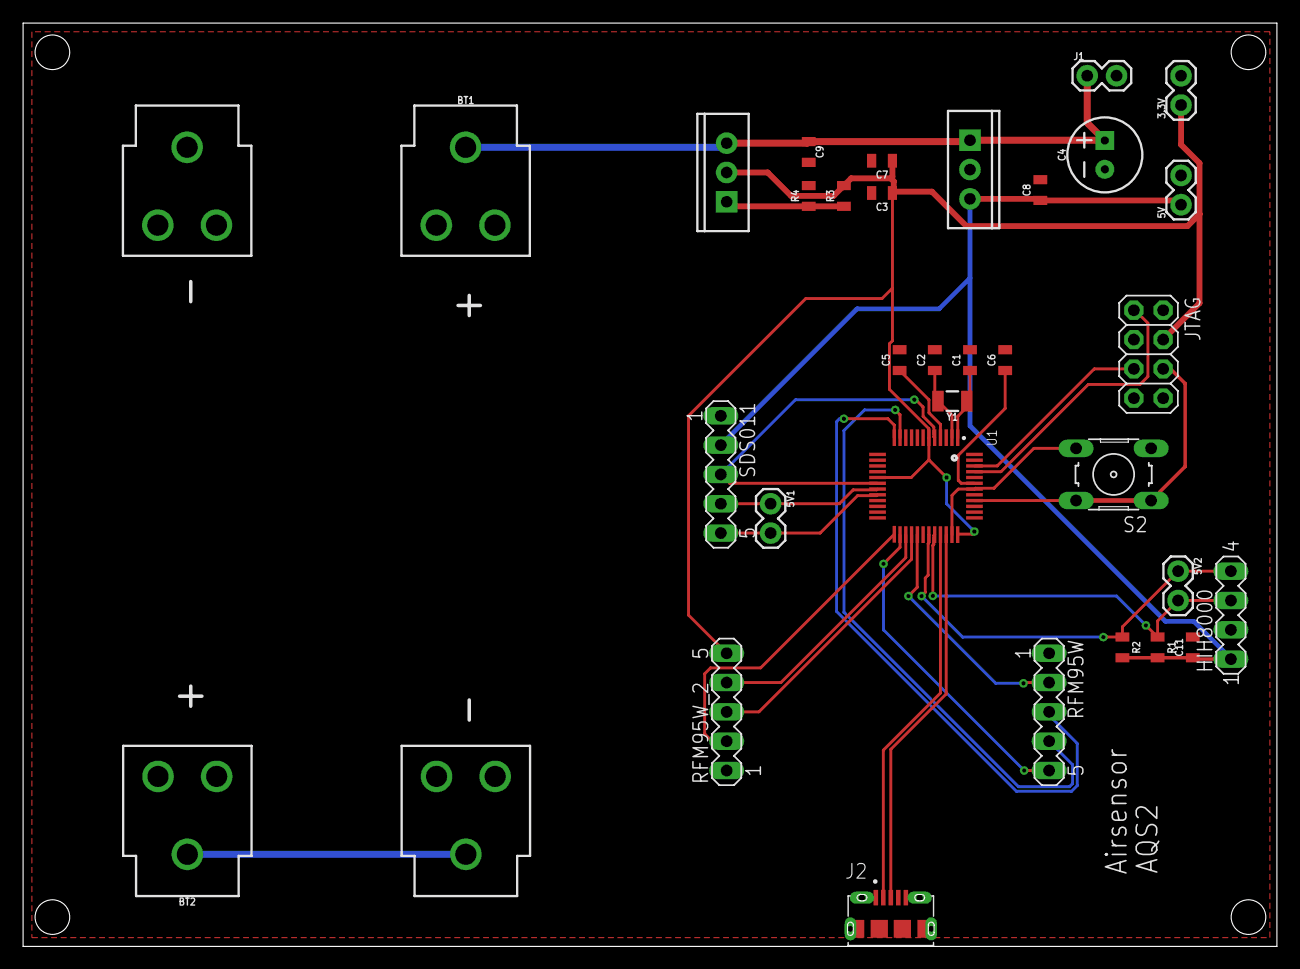
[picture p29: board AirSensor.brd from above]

Board: 2 copper layers, 108.6 x 80.0 mm, 32 parts (0 on the bottom side), 26 nets.

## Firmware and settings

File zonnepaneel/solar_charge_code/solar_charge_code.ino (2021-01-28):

// ARDUINO SOLAR CHARGE CONTROLLER
//Version-2.0
//by deba168,INDIA
//Dated : 22/10/2014


#include <Wire.h>
//#include <LiquidCrystal_I2C.h>
#define SOL_ADC A0     // Solar panel side voltage divider is connected to pin A0 
#define BAT_ADC A1    // Battery side voltage divider is connected to pin A1
#define CURRENT_ADC A2  // ACS 712 current sensor is connected to pin A2
#define TEMP_ADC A3   // LM 35 Temperature is connected to pin A3
#define AVG_NUM 10    // number of iterations of the adc routine to average the adc readings
#define BAT_MIN 6  // minimum battery voltage for 7.4V system
#define BAT_MAX 8.4  // maximum battery voltage for 7.4V system
#define BULK_CH_SP 7.8 // bulk charge set point for sealed lead acid battery // flooded type set it to 14.6V
#define FLOAT_CH_SP 7.6  //float charge set point for lead acid battery
#define LVD 7          //Low voltage disconnect setting for a 7V system
#define PWM_PIN 3        // pin-3 is used to control the charging MOSFET //the default frequency is 490.20Hz
#define CURRENT_CHECK 2       // pin-2 is used to control the current
#define BAT_RED_LED 5
#define BAT_GREEN_LED 8
#define BAT_YELLOW_LED 7
#define LOAD_RED_LED 9
#define LOAD_GREEN_LED 10

//--------------------------------------------------------------------------------------------------------------------------
///////////////////////DECLARATION OF ALL GLOBAL VARIABLES//////////////////////////////////////////////////////////////////
//--------------------------------------------------------------------------------------------------------------------------
float solar_volt = 0;
float bat_volt = 0;
float load_current = 0;
int temperature = 0;
int temp_change = 0;
float system_volt = 0;
float bulk_charge_sp = 0;
float float_charge_sp = 0;
float charge_status = 0;
float load_status = 0;
float error = 0;
float Ep = 0;
int duty = 0;
float lvd;
float msec = 0;
float last_msec = 0;
float elasped_msec = 0;
float elasped_time = 0;
float ampSecs = 0;
float ampHours = 0;
float watts = 0;
float wattSecs = 0;
float wattHours = 0;


//******************************************************* MAIN PROGRAM START ************************************************
void setup()
{

  Serial.begin(9600);
  pinMode(BAT_RED_LED, OUTPUT);
  pinMode(BAT_GREEN_LED, OUTPUT);
  pinMode(BAT_YELLOW_LED, OUTPUT);
  pinMode(LOAD_RED_LED , OUTPUT);
  pinMode(LOAD_GREEN_LED, OUTPUT);
  pinMode(PWM_PIN, OUTPUT);
  pinMode(CURRENT_CHECK,INPUT);
  digitalWrite(PWM_PIN, LOW); // default value of pwm duty cycle
}

  void loop()
  {
    digitalWrite(BAT_YELLOW_LED, HIGH);
    read_data();             // read different sensors data from analog pin of arduino
    system_voltage();        // detect the system voltage according to battery voltage
    setpoint();      // decide the charge set point according to system voltage
    charge_cycle();         // pwm charging of battery
    power();                // calculate the load power and energy
    led_indication();       // led indica
    print_data();            // print in serial monitor
    digitalWrite(BAT_YELLOW_LED, LOW);

   
  }
  //************************************************************ PROGRAM END *************************************************


  //------------------------------------------------------------------------------------------------------
  ////////////////// READS AND AVERAGES THE ANALOG INPUTS (SOLRAR VOLTAGE,BATTERY VOLTAGE)////////////////
  //------------------------------------------------------------------------------------------------------
  int read_adc(int adc_parameter)
  {

    int sum = 0;
    int sample ;
    for (int i = 0; i < AVG_NUM; i++)
    { // loop through reading raw adc values AVG_NUM number of times
      sample = analogRead(adc_parameter);    // read the input pin
      sum += sample;                        // store sum for averaging
      delayMicroseconds(50);              // pauses for 50 microseconds
    }
    return (sum / AVG_NUM);               // divide sum by AVG_NUM to get average and return it
  }
  //-------------------------------------------------------------------------------------------------------------
  ////////////////////////////////////READ THE DATA//////////////////////////////////////////////////////////////
  //-------------------------------------------------------------------------------------------------------------
  void read_data(void)
  {
    //5V = ADC value 1024 => 1 ADC value = (5/1024)Volt= 0.0048828Volt
    // Vout=Vin*R2/(R1+R2) => Vin = Vout*(R1+R2)/R2   R1=100 and R2=20
    solar_volt = read_adc(SOL_ADC) * 0.00488 * (120 / 20);
    bat_volt   = read_adc(BAT_ADC) * 0.00488 * (120 / 20);
    load_current = (read_adc(CURRENT_ADC) * .0488 - 25);
    temperature = read_adc(TEMP_ADC) * 0.00488 * 100;

  }
  //------------------------------------------------------------------------------------------------------------
  /////////////////////////////////POWER AND ENERGY CALCULATION //////////////////////////////////////////////
  //------------------------------------------------------------------------------------------------------------
  void power(void)

  {
    msec = millis();
    elasped_msec = msec - last_msec; //Calculate how long has past since last call of this function
    elasped_time = elasped_msec / 1000.0; // 1sec=1000 msec
    watts = load_current * bat_volt; //Watts now
    ampSecs = (load_current * elasped_time); //AmpSecs since last measurement
    wattSecs = ampSecs * bat_volt; //WattSecs since last measurement
    ampHours = ampHours + ampSecs / 3600; // 1 hour=3600sec //Total ampHours since program started
    wattHours = wattHours + wattSecs / 3600; // 1 hour=3600sec //Total wattHours since program started
    last_msec = msec; //Store 'now' for next time
  }

  //------------------------------------------------------------------------------------------------------------
  /////////////////////////////////PRINT DATA IN SERIAL MONITOR/////////////////////////////////////////////////
  //------------------------------------------------------------------------------------------------------------
  void print_data(void)
  {
    delay(100);
    Serial.print("Solar Panel Voltage: ");
    Serial.print(solar_volt);
    Serial.println("V");
    Serial.print("Battery Voltage: ");
    Serial.print(bat_volt);
    Serial.println("V");
    Serial.print("Syestem Voltage: ");
    Serial.print(system_volt);
    Serial.println("V");
    Serial.print("Charge Set Point:");
    Serial.println(bulk_charge_sp);
    Serial.print("Temperature:");
    Serial.print(temperature);
    Serial.println("C");
    Serial.print("Load Current: ");
    Serial.print(load_current);
    Serial.println("A");
    Serial.print("Power: ");
    Serial.print(watts);
    Serial.println("W");
    Serial.print("Energy: ");
    Serial.print(wattHours);
    Serial.println("WH");
    Serial.print("Duty Cycle :");
    if (charge_status == 1)
    {
      Serial.println("99%");
      Serial.println("BULK CHARGING");
    }
    else if (charge_status == 2)
    {
      Serial.print(Ep);
      Serial.println("%");
      Serial.println("FLOAT CHARGING");
    }
    else
    {
      Serial.println("0%");
      Serial.println("NOT CHARGING");
    }
    if (load_status == 1)
    {
      Serial.println("LOAD IS CONNECTED");
    }
    else
    {
      Serial.println("LOAD IS DISCONNECTED");
    }

    Serial.println("***************************");
  }
  //----------------------------------------------------------------------------------------------------------------------
  //////////////////////////////////SYSTEM VOLTAGE AUTO DETECT ///////////////////////////////////////////////////////////
  //----------------------------------------------------------------------------------------------------------------------
  void system_voltage(void)
  {
    if ((bat_volt > BAT_MIN) && (bat_volt < BAT_MAX))
    {
      system_volt = 12;
    }
    /*
      else if  ((bat_volt > BAT_MIN*2 ) && (bat_volt < BAT_MAX*2))
      {
      system_volt=24;
      }*/
    else if ((bat_volt > BAT_MIN / 2 ) && (bat_volt < BAT_MAX / 2))
    {
      system_volt = 6;
    }

  }
  //---------------------------------------------------------------------------------------------------------------------------
  ////////////////////////////////////CHARGE SET POINT ///////////////////////////////////////////////////////////////////////
  //---------------------------------------------------------------------------------------------------------------------------

  void setpoint(void)
  {
    temp_change = temperature - 25.0; // 25deg cel is taken as standard room temperature
    // temperature compensation = -5mv/degC/Cell
    // If temperature is above the room temp ;Charge set point should reduced
    // If temperature is bellow the room temp ;Charge set point should increased
    if (system_volt == 12)
    {
      bulk_charge_sp = BULK_CH_SP - (0.030 * temp_change) ;
      float_charge_sp = FLOAT_CH_SP - (0.030 * temp_change) ;
      lvd = LVD;
    }

    else if (system_volt == 6)
    {
      bulk_charge_sp = (BULK_CH_SP / 2) - (0.015 * temp_change) ;
      float_charge_sp = (FLOAT_CH_SP / 2) - (0.015 * temp_change) ;
      lvd = LVD / 2;
    }
    /*
      else if (system_volt == 24)
      {
      bulk_charge_sp = (BULK_CH_SP*2)-(0.060*temp_change) ;
      float_charge_sp= (FLOAT_CH_SP*2)-(0.060*temp_change) ;
      lvd=LVD*2;
      }
    */

  }
  //--------------------------------------------------------------------------------------------------------------------------------
  ///////////////////////////////////////////////////PWM CHARGE CYCLE @500 HZ //////////////////////////////////////////////////
  //-------------------------------------------------------------------------------------------------------------------------------
  void charge_cycle(void)
  {
    if (solar_volt > bat_volt && bat_volt <= bulk_charge_sp)
    {


      if (bat_volt <= float_charge_sp || digitalRead(CURRENT_CHECK) == HIGH) // charging start
      {
        charge_status = 1; // indicate the charger is in BULK mode
        duty = 252.45;
        analogWrite(PWM_PIN, duty); // 99 % duty cycle // rapid charging


      }
      else if (bat_volt > float_charge_sp && bat_volt <= bulk_charge_sp)
      {
        charge_status = 2; // indicate the charger is in FLOAT mode
        error  = (bulk_charge_sp - bat_volt);      // duty cycle reduced when the battery voltage approaches the charge set point
        Ep = error * 100 ; //Ep= error* Kp // Assume  Kp=100

        if (Ep < 0)
        {
          Ep = 0;
        }
        else if (Ep > 100)
        {
          Ep = 100;
        }
        else if (Ep > 0 && Ep <= 100) // regulating
        {
          duty = (Ep * 255) / 100;
        }
        analogWrite(PWM_PIN, duty);
      }
    }
    else
    {
      charge_status = 0; // indicate the charger is OFF
      duty = 0;
      analogWrite(PWM_PIN, duty);
    }
  }



  //-------------------------------------------------------------------------------------------------
  //////////////////////////LED INDICATION////////////////////////////////////
  //-------------------------------------------------------------------------------------------------
  void led_indication(void)
  {
    battery_led();           //Battery status led indication
    //load_led();              //Load led indication
  }

  //----------------------------------------------------------------------------------------------------------------------
  /////////////////////////////////////////////BATTERY LED INDICATION/////////////////////////////////////////////////////
  //----------------------------------------------------------------------------------------------------------------------
  void battery_led(void)
  {
    
    if ( (bat_volt > system_volt) && ( bat_volt < bulk_charge_sp))
    {
      leds_off_all();
      digitalWrite(BAT_YELLOW_LED, HIGH); // battery voltage is healthy
    }
    else if (bat_volt >= BULK_CH_SP)
    {
      leds_off_all();
      digitalWrite(BAT_GREEN_LED, HIGH); //battery is fully charged
    }
    else if (bat_volt < BAT_MIN)
    {
      leds_off_all();
      digitalWrite(BAT_RED_LED, HIGH); // battery voltage low
    }
    
  }
  //----------------------------------------------------------------------------------------------------------------------
  /////////////////////////////////////////////LOAD LED INDICATION/////////////////////////////////////////////////////
  //----------------------------------------------------------------------------------------------------------------------

  void load_led()
  {
    if (load_status == 1)
    {
      digitalWrite(LOAD_GREEN_LED, HIGH);
    }
    else if (load_status == 0)
    {
      digitalWrite(LOAD_RED_LED, HIGH);
    }
  }

  //------------------------------------------------------------------------------------------------------
  //////////////////////// TURN OFF ALL THE LED///////////////////////////////////////////////////////////
  //------------------------------------------------------------------------------------------------------
  void leds_off_all(void)
  {

    digitalWrite(BAT_RED_LED, LOW);
    digitalWrite(BAT_GREEN_LED, LOW);
    digitalWrite(BAT_YELLOW_LED, LOW);
    digitalWrite(LOAD_RED_LED, HIGH);
    digitalWrite(LOAD_GREEN_LED, HIGH);
  }

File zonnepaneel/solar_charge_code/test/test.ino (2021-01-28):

int led = 6;
int led2 = 4;
int switch1 = 2;
int switch2 = 3;
int buttonState;
int buttonState2;
void setup() {
  //Serial.begin(9600);
  pinMode(led,OUTPUT); //pin als output
  pinMode(led2,OUTPUT);
  pinMode(switch1, INPUT);
  pinMode(switch2, INPUT);
} 

void loop() {
  buttonState = digitalRead(switch1);
  buttonState2 = digitalRead(switch2);
  
 if (buttonState == LOW)
 {
  digitalWrite(led, HIGH);
  digitalWrite(led2 ,LOW);
 }
 
 if (buttonState2 == LOW)
 {
  digitalWrite(led2, HIGH);
  digitalWrite(led, LOW);
 }
 
}

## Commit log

2020-10-04 Added schema of sensors and SAMD21G
    [AirSensor.sch]
2020-10-16 added all 3 schematics en all 3 PCB deigns
    [AirSensor.brd, AirSensor.sch, AirSensor_HIH8xxx.brd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]
2020-10-21 added JTAG schematic and PCB + all pictures
    [AirSensor.brd, AirSensor.sch, AirSensor_HIH8xxx.sch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]
2020-10-21 added pictures of schematic, PCB and 3D model to read.me file
2020-10-22 updated JTAG schematic PCB and 3D model
2020-10-26 added Gerber files in map
    [copper_bottom.gbr, copper_top.gbr, drill_1_16.xln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]
2020-11-03 box en deksel in 3d tekening gemaakt
    [box.ipt, cap.ipt]
2020-12-09 nieuw schema lora bordje
    [AirSensor_LoRA.sch]
2020-12-11 feedback verwerking
    [AirSensor.brd, AirSensor.sch, AirSensor_HIH8xxx.brd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]
2020-12-11 added gerber files
    [copper_bottom.gbr, copper_top.gbr, drill_1_16.xln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]
2020-12-14 fixed some bugs
    [copper_bottom.gbr, copper_top.gbr, drill_1_16.xln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]
2020-12-14 stl en gcode files toegevoegd
    [box.stl, cap.stl]
2021-01-28 added solar charger, PCB image, ...
    [AirSensor.brd, AirSensor.sch, Solar_Charger.brd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]
2021-02-02 rx/tx fout opgelost in PCB
    [AirSensor_LoRA.brd]

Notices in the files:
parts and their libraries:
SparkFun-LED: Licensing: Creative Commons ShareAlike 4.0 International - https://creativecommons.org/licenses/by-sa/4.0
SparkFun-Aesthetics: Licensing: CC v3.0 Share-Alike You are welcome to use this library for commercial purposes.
